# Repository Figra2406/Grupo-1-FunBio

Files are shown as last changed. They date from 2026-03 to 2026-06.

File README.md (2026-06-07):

# Grupo-1-FunBio
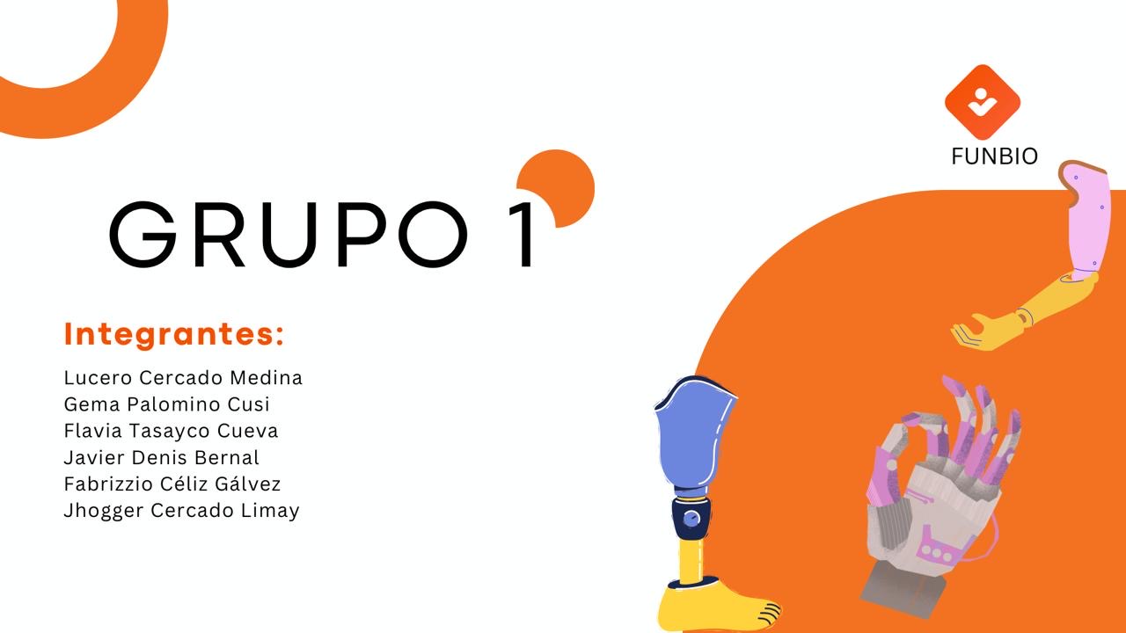
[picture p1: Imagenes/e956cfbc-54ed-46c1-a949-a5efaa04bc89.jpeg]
presentación

# Descripción de grupo
Grupo con el propósito de crear soluciones innovadoras en el area de ....., trabajando de forma colaborativa en el diseño y desarrollo del proyectos. 

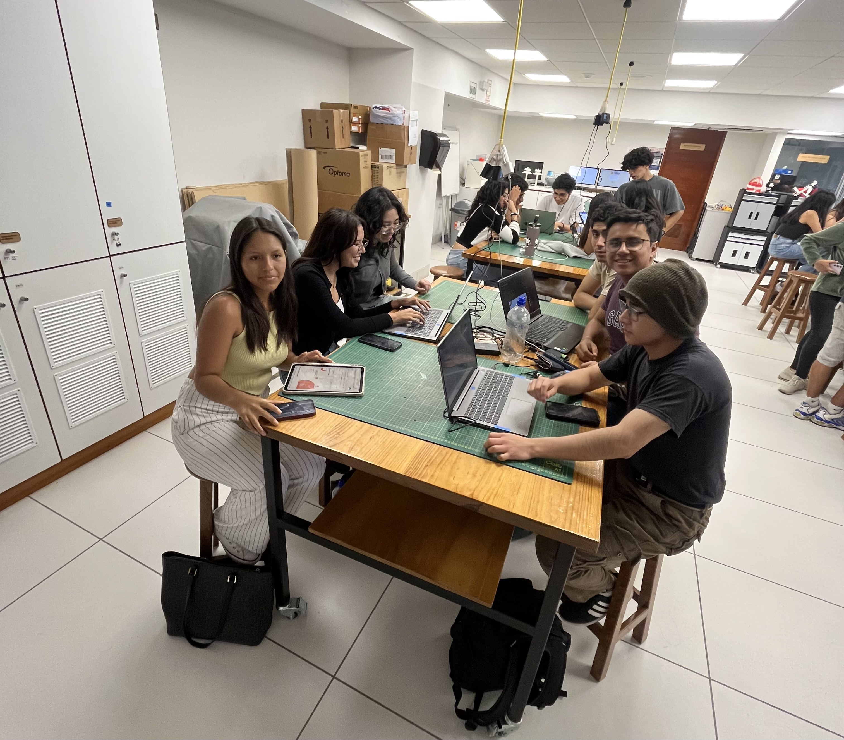
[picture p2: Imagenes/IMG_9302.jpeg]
Foto Grupal

Grupo enfocado en crear soluciones en el area de salud ante..., trabajando de forma colaborativa en el diseño y desarrollo del proyectos.
# Integrantes del Equipo y Roles
1. Lucero Cercado Medina
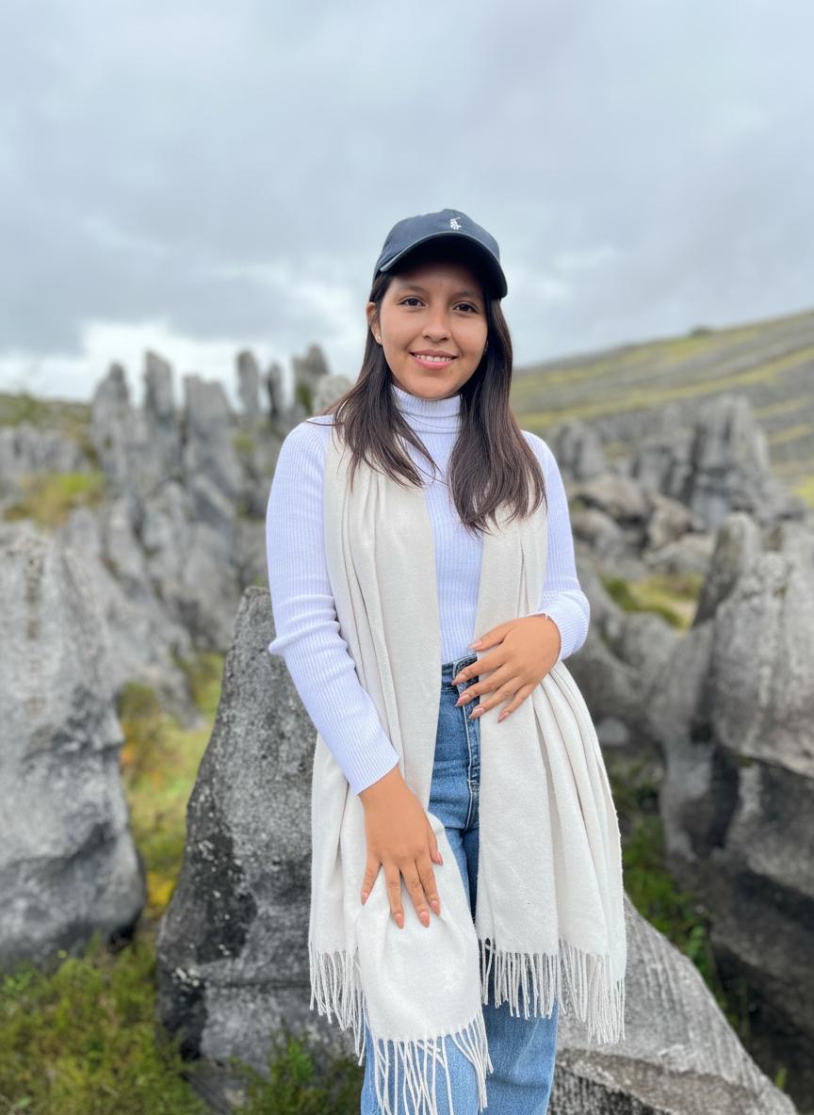
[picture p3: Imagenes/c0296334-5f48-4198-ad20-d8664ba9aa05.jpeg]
Lucero
   
   * **Edad:** 18 años
   * **Sobre mí:** Me interesa ingenieria de materiales y tejidos 
   * **Rol:** Impresión
   * **Responsabilidades:** Supervisar el proceso de impresión
3. Gema Palomino Cusi
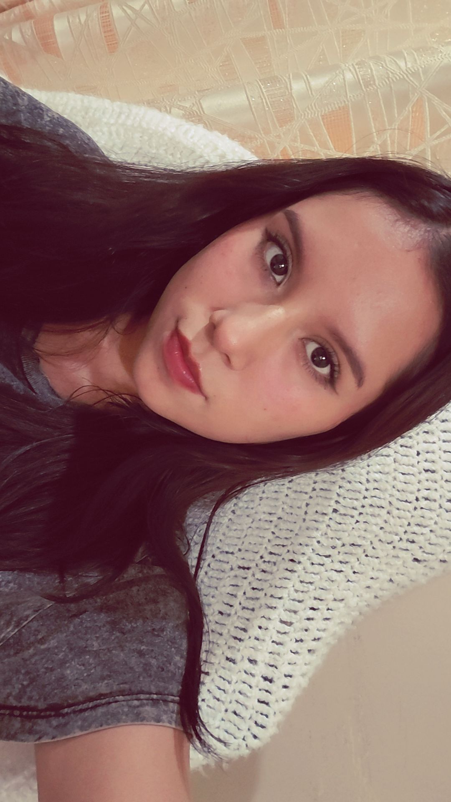
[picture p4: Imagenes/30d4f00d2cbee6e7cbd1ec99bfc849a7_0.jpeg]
Gema
   
   * **Edad:** 20 años
   * **Sobre mí:** Estudiante Biomédica PUCP-UPCH
   * **Rol:** Gestión 
   * **Responsabilidades:**
5. Flavia Tasayco Cueva
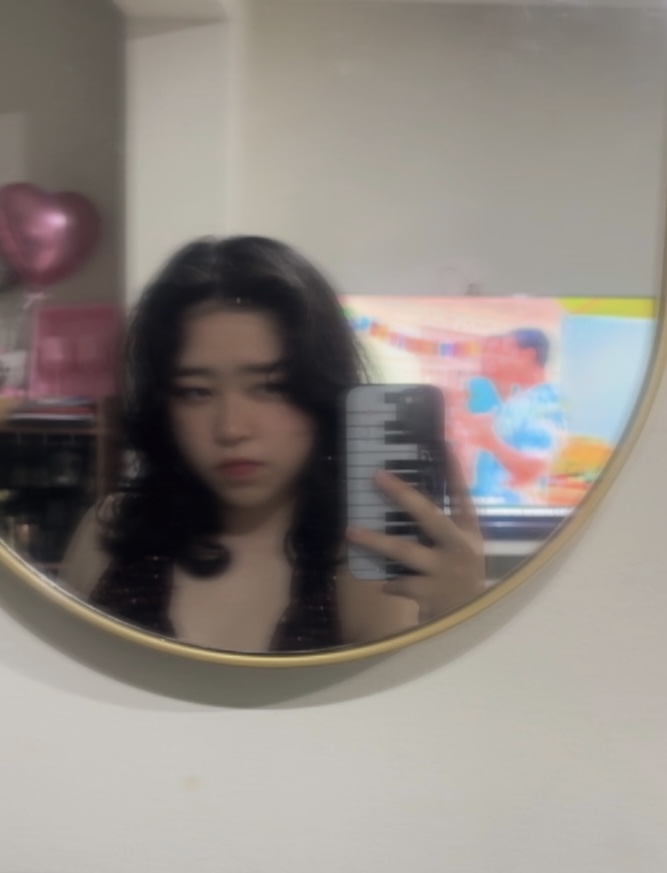
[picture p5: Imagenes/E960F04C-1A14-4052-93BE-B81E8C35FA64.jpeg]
Flavia
   
   * **Edad:** 19 años 
   * **Sobre mí:** Estudiante Biomédica PUCP-UPCH
   * **Rol:** Redacción
   * **Responsabilidades:**
7. Javier Bernal Garayar
   
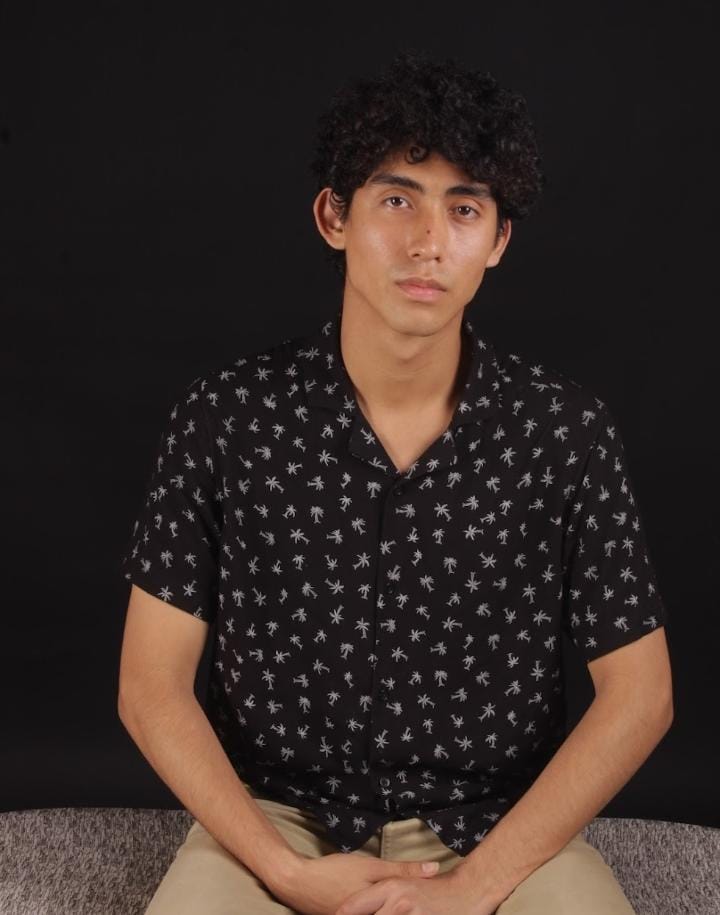
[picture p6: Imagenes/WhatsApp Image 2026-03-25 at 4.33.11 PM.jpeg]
Javier
   .
   * **Edad:** 24 años
   * **Sobre mí:**
   * **Rol:** Apoyo
   * **Responsabilidades:**
9. Fabrizzio Céliz Gálvez
    
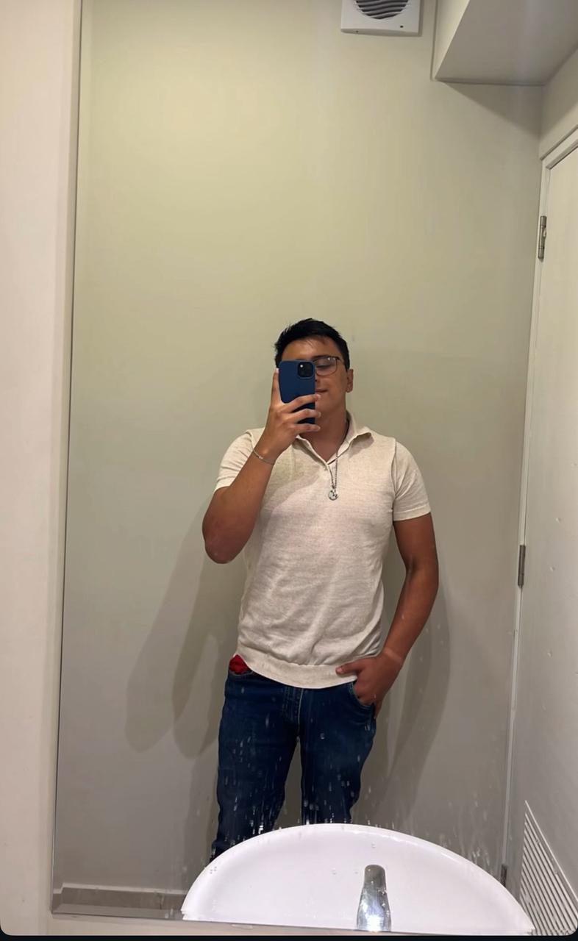
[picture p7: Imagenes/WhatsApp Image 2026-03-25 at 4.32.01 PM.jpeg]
Fabrizzio
   
   * **Edad:** 20 
   * **Sobre mí:** Estudiante de Ingenieria Biomedica PUCP-UPCH 
   * **Rol:** Diseñado y modelado 3D
   * **Responsabilidades:** 
11. Jhogger Cercado Limay

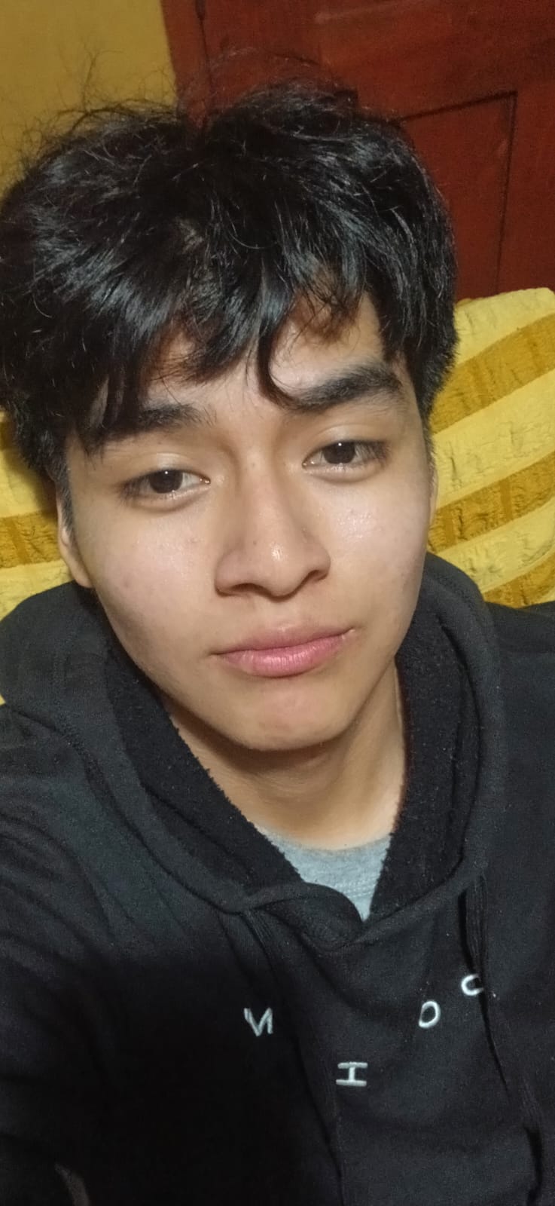
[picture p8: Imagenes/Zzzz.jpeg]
Jhogger
   .
   * **Edad:** 19 
   * **Sobre mí:**
   * **Rol:** 
   * **Responsabilidades:**

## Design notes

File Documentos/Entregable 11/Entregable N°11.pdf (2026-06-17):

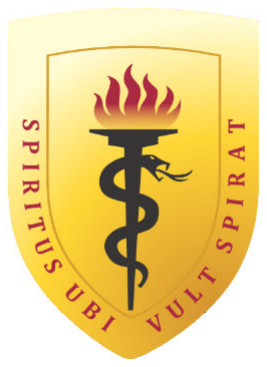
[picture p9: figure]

## FUNDAMENTOS DE BIODISEÑO

## Entrega N°11: Integración Hardware - Software - Manufactura Digital

## Grupo 1

## Integrantes: Fabrizzio Marcel Céliz Gálvez Jhogger Cercado Limay Ximena Gema Palomino Cusi Flavia Sharick Tasayco Cueva Javier Denis Bernal Garayar Lucero Rubi Cercado Medina

16/06/26

### 1. Verificación de diseño (Software):

Funcionalidad | Requerimiento | Resultado esperado | Resultado obtenido | ¿Cump le? | Observaciones
Inicio del sistema | El sistema debe iniciar el ciclo de alivio de presión de forma controlada. | Al encender el dispositivo, el programa debe iniciar sin activar accidentalmente bombas y servos. | En el código se inician los pines del ESP32 y se apagan bombas, válvulas/servos y buzzer antes de iniciar el ciclo. | Si | Se recomienda mantener esta condición inicial para evitar activaciones inesperadas al conectar la fuente
Activación del buzzer | El sistema debe indicar el inicio del periodo de alivio de presión. | El buzzer debe emitir una alerta antes de iniciar la terapia. | En el prototipo electrónico se evidencia que el buzzer se enciende por 2 segundos para advertir el inicio de la terapia. | Si | Esta función permite avisar al usuario o cuidador que el sistema comenzará a operar.
Activación de bombas de aire | El sistema debe inflar las bolsas de aire para redistribuir la presión. | Las bombas deben encenderse durante un tiempo programado para inflar los cojines. | En el prototipo electrónico se evidencia que las bombas de aire se encienden por 10 segundos para inflar los cojines. | Si | Se verificó el encendido de las bombas; falta medir presión o volumen de inflado para saber si es suficiente para uso real.
Control del tiempo de inflado | El sistema debe medir el tiempo de descarga mediante un cronómetro automático. | El software debe controlar automáticament e cuánto tiempo permanecen activas las bombas. | El código utiliza tiempos programados para inflado, mantenimiento, desinflado y espera. | Si | Se logró conseguir un rango de desinflado pero
Tiempo de terapia | El sistema debe mantener la redistribución de presión durante un periodo terapéutico. | Luego del inflado, las bolsas deben mantenerse infladas durante un tiempo determinado. | En el código realizado se utiliza un tiempo de 20 segundos para poder realizar pruebas pero se idea que se aumente a 3 minutos | Parcial mente | Falta evidenciar con una prueba completa que el sistema mantenga la presión durante el tiempo terapéutico planteado de aproximadamente 240 segundos.
Alerta sonora antes del descenso | El sistema debe emitir una alerta sonora al finalizar el tiempo programado de | El buzzer debe indicar que la terapia terminará y que el sistema retornará a su | En el prototipo electrónico se evidencia que el buzzer vuelve a activarse por 3 segundos antes del | Si | Esta función es necesaria porque anticipa el cambio de estado del sistema.

| alivio de presión. | estado inicial. | descenso del paciente.
Control del desinflado | El sistema debe permitir el retorno del usuario a la posición inicial después del periodo de descarga. | Los servos o válvulas deben liberar el aire de forma lenta y segura. | Los servos activan una pinza sobre uno de los tubos para liberar el aire de manera controlada. | Parcial mente | El mecanismo funciona de forma preliminar, pero falta medir el tiempo real de desinflado y comprobar si ambos cojines se desinflan de forma uniforme
Control bluetooth | El dispositivo debe permitir el accionamiento mediante control remoto o Bluetooth. | El usuario o cuidador debe poder iniciar el ciclo sin manipular directamente el circuito. | Se ha planteado el desarrollo de una aplicación para una interfaz bluetooth pero aún falta la implementación | No | El desarrollo de la aplicación se está realizando con diferentes pruebas pero por ahora su funcionalidad está enfocada principalmente en Android.
Detección de fallas del driver | El sistema debe operar de manera segura ante fallas eléctricas o de actuadores. | Si el DRV8833 detecta una falla, el sistema debe apagar bombas y activar un modo de emergencia. | En el código del se incluye una función de detección de falla mediante el pin NFAULT y un modo de emergencia que apaga bombas y abre válvulas. | Parcial mente | La función está programada en en el código pero aun faltan hacer pruebas de fallo y ajustar el prototipo para poder saber cómo actuará en estas situaciones desafortunadas.
Retorno al estado inicial | El sistema debe permitir que el usuario vuelva a la posición inicial luego del alivio de presión. | Al finalizar el ciclo, las bombas deben apagarse y el aire debe liberarse de manera controlada. | El prototipo apaga las bombas y activa los servos para liberar aire. | Parcial mente | Se verificó de forma preliminar, pero falta comprobar con carga o peso representativo si el retorno es seguro y estable.
Apagado del sistema | El cuidador o usuario debe poder apagar el sistema cuando sea necesario. | El sistema debe contar con una forma clara de apagado o interrupción. | En el diseño electrónico inicial se planea el uso de un switch de encendido pero aun no se han realizado pruebas finales. | Parcial mente | Se recomienda incluir un interruptor general accesible y una prueba de apagado seguro de energía.

### 2. Verificación de diseño (Hardware):

Requerimiento del diseño | Componen te evaluado | Pruebas realizadas | Resultados | ¿Cum ple? | Observaciones
El sistema debe controlar automáticament e el ciclo de alivio de presión | ESP32 | Verificar que el ESP32 pueda controlar buzzer, bombas y servos/válvulas | El ESP32 es usado como unidad de control y su funcionalidad es positiva. | Si | Se mantiene el ESP32 como controlador principal por su capacidad de control y posible conexión Bluetooth.
El sistema debe activar las bombas de aire | Bombas de aire | Verificar encendido de las bombas durante el tiempo programado | En el prototipado electrónico las bombas se activan por 10 segundos para inflar los cojines. | Si | Falta medir caudal, presión generada y tiempo necesario para inflado con carga real (aproximadamente es un tiempo menor)
El sistema debe controlar la etapa de potencia de las bombas | DRV8833 | Verificar que el driver permita el control de las bombas desde el microcontrolador. | El DRV8833 se usa como control principal de las bombas. | Si | Se debe cuidar que la corriente requerida por las bombas no supere la capacidad del driver.
El sistema debe redistribuir presión en la zona sacrocoxígea | Bolsas de aire | Verificar que las bolsas se inflen y se ubiquen a ambos lados de la región glútea. | Se usan dos bolsas de aire ubicadas en el asiento para redistribuir la presión. | Parcia lment e | Falta medir presión de contacto o realizar una prueba con carga para comprobar la redistribución real.
El sistema debe liberar el aire de forma controlada | Servomotor es | Verificar que el servo accione la pinza y permita el desinflado lento. | Se evidencia que los servos giran la pinza ubicada en el tubo de liberación de aire. | Parcia lment e | El mecanismo funciona, pero se debe mejorar la precisión mecánica y asegurar que el tubo no se dañe por presión repetida.
El diseño inicial consideraba válvulas solenoides | Válvulas solenoides | Verificar si se implementa la válvula en el prototipo final. | Previamente se pensó en el uso de una válvula solenoide, pero en el prototipo electrónico final se reemplaza funcionalmente por servos y pinza | No | Se considera un cambio de diseño. El uso de servos permitió una liberación mecánica del aire más accesible para el prototipo actual.
El sistema debe emitir señales auditivas | Buzzer | Verificar que el buzzer se active al inicio y antes del descenso. | El buzzer se activó por 2 segundos al inicio y por 3 | Si | Se recomienda mantenerlo como señal de seguridad para el cuidador y

| | | segundos antes de finalizar la terapia. | | usuario.
El sistema debe contar con alimentación eléctrica adecuada | Bateria | Verificar si la fuente o batería alimenta al ESP32, bombas y servos sin fallas. | Se plantea el uso de una batería recargable pero no se reporta una medición de autonomía ni caída de voltaje. | Parcia lment e | Falta medir autonomía, consumo total y estabilidad de voltaje.
El sistema debe proteger los componentes eléctricos | Fusible, Switch, Capacitores | Verificar la presencia de elementos básicos de protección y encendido. | Se considera bloque de alimentación, fusible, switch y capacitores. | Si | Falta comprobar la protección real ante sobrecorriente y mejorar el aislamiento de cables para un mejor uso.
El prototipo debe ser portátil y adaptable a una silla de ruedas | Carcasa | Verificar que la carcasa integre los componentes principales. | Se diseñó una carcasa rectangular con tapa desmontable, alojamientos para protoboard, batería, servos, bombas y regulador. | Parcia lment e | El diseño original planteado se mandó a imprimir pero aun falta las primeras pruebas de implementación de medidas.
Los componentes internos deben mantenerse fijos | Soportes internos | Verificar puntos de fijación para bombas, servos y protoboard. | El diseño de la carcasa incluye alojamientos y soportes atornillados para reducir desplazamiento s. | Parcia lment e | Falta prueba física de vibración o movimiento durante el funcionamiento.
El sistema debe permitir conexión de tubos hacia los cojines. | Mangueras | Verificar existencia de entradas/salidas para tubos. | La carcasa cuenta con dos orificios para los tubos que conectan cojines, bombas y servomotores. | Si | Se recomienda revisar que el radio de las mangueras no obstruya el flujo de aire.
El sistema debe mantener la estabilidad del usuario durante la elevación o redistribución | Bolsas de aire | Verificar que el usuario no se desplace durante el ciclo. | Aún no se evidencia una prueba con usuario real ni con peso equivalente. | No | Se deben realizar pruebas con pesos reales y finalmente con una persona con un peso considerable.

El sistema debe operar sin trasladar al usuario fuera de la silla | Implementa ción del prototipado | Verificar que el sistema pueda colocarse sobre el asiento de una silla convencional. | El concepto plantea un dispositivo portátil colocado sobre la silla de ruedas sin modificarla permanentemen te. | Parcia lment e | Faltan pruebas del prototipo instalado en una silla de ruedas real.
El sistema debe cumplir criterios básicos de seguridad | Integración completa | Verificar ausencia de movimientos bruscos, cables expuestos y calentamiento. | No se han realizado pruebas de temperatura, presión máxima, estabilidad corporal ni seguridad eléctrica completa. | Parcia lment e | Se recomienda realizar pruebas de calentamiento, estabilidad, deslizamiento, fugas de aire y funcionamiento prolongado.

### 3. Tabla de verificación del prototipo

FUNCIONALIDAD | CUMPLIMIENTO
SI | NO

El dispositivo infla las bolsas de aire mediante bombas de 6 V.

El dispositivo desinfla las bolsas de aire cuando se envía la orden correspondiente.

El ESP32 recibe comandos desde la aplicación móvil mediante Bluetooth.

La aplicación permite controlar manualmente el inflado y desinflado de las bolsas.

El sistema distribuye la presión alternadamente entre las zonas de apoyo.

El dispositivo funciona con batería recargable.

El sistema monitorea la presión interna de las bolsas mediante sensores.

El dispositivo evita sobrepresiones mediante límites programados.

La aplicación muestra el estado de funcionamiento del dispositivo.

El sistema almacena o transmite datos para su monitoreo.

4. Tabla de requerimientos iniciales, finales y resultados de test.
Requerimientos de diseños iniciales | Requerimientos de diseños finales | Expectativas del test
El sistema debe reducir la presión continua sobre la zona glútea del paciente. | Se implementaron dos bolsas de aire independientes controladas electrónicamente para redistribuir la presión. | Se verificó el llenado de presión entre ambas bolsas durante el funcionamiento.
El dispositivo debe ser portátil. | Se utilizó una batería recargable como fuente principal de alimentación. | Se espera que el sistema opere correctamente sin conexión directa a la red eléctrica.
Debe existir control inalámbrico del sistema. | Se implementó comunicación Bluetooth mediante ESP32 y una aplicación desarrollada en MIT App Inventor. | Se tiene la expectativa de que la conexión entre aplicación y dispositivo sea estable dentro del rango de operación.
El usuario debe poder inflar y desinflar las bolsas manualmente. | Se añadieron botones de control en la aplicación móvil. | Los comandos fueron creados y esperan ser ejecutados correctamente por las bombas neumáticas.
El dispositivo debe proteger al usuario frente a presiones excesivas. | Se programaron límites máximos de presión y rutinas de seguridad. | El sistema debería detener el inflado al alcanzar el valor establecido.
El equipo debe ser fácil de utilizar. | La interfaz móvil se diseñó con controles simples e indicadores de estado. | Los usuarios deberían operar el sistema sin capacitación extensa.
Debe permitir futuras ampliaciones del sistema. | El ESP32 proporciona suficientes entradas y salidas para incorporar nuevos sensores y funciones. | Se comprobó la posibilidad de integrar módulos adicionales.
El sistema debe ser de bajo costo. | Se emplearon componentes comerciales de fácil adquisición. | El costo estimado resultó inferior al de sistemas clínicos especializados.
Debe contribuir a la prevención de úlceras por presión. | El prototipo realiza cambios periódicos en la distribución de cargas mediante variaciones de presión. | Se espera una reducción de los puntos de presión estáticos durante las pruebas preliminares.

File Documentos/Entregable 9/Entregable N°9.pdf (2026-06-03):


## FUNDAMENTOS DE BIODISEÑO

## Entrega N°9: Modelado 3D y avance del prototipado electrónico.Plan de usabilidad basado en evidencias

## Grupo 1

## Integrantes: Fabrizzio Marcel Céliz Gálvez Jhogger Cercado Limay Ximena Gema Palomino Cusi Flavia Sharick Tasayco Cueva Javier Denis Bernal Garayar Lucero Rubi Cercado Medina

26/05/26

Hardware Electronico.
1)Diseño esquemático del circuito electrónico:

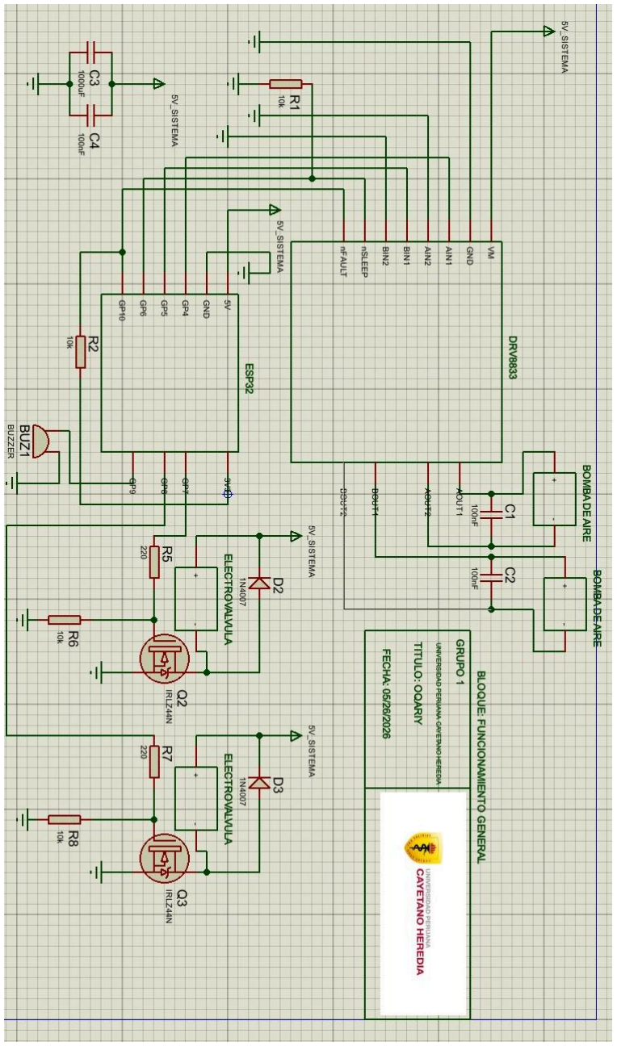
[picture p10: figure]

Software:
Script de programación:

const int PIN_BOMBA_IZQ = 4; const int PIN_BOMBA_DER = 5; const int PIN_NSLEEP = 6;

const int PIN_VALVULA_IZQ = 7; const int PIN_VALVULA_DER = 8;

const int PIN_BUZZER = 9;
const int PIN_NFAULT = 10;

const unsigned long TIEMPO_INFLADO = 8000; const unsigned long TIEMPO_MANTENER = 10000; const unsigned long TIEMPO_DESINFLADO = 5000; const unsigned long TIEMPO_ESPERA = 15000;

void setup() {
pinMode(PIN_BOMBA_IZQ, OUTPUT); pinMode(PIN_BOMBA_DER, OUTPUT); pinMode(PIN_NSLEEP, OUTPUT);

pinMode(PIN_VALVULA_IZQ, OUTPUT); pinMode(PIN_VALVULA_DER, OUTPUT);

pinMode(PIN_BUZZER, OUTPUT); pinMode(PIN_NFAULT, INPUT);

apagarBombas();
cerrarValvulas();
apagarBuzzer();

digitalWrite(PIN_NSLEEP, LOW);

delay(1000);
beep(200);
}

void loop() {
if (hayFallaDRV()) {
modoEmergencia();
return;
}

beep(100);
habilitarDRV();
cerrarValvulas();
encenderBombas();

unsigned long inicioInflado = millis();

while (millis() - inicioInflado < TIEMPO_INFLADO) { if (hayFallaDRV()) {
modoEmergencia();
return;

}
}

apagarBombas();

unsigned long inicioMantener = millis();

while (millis() - inicioMantener < TIEMPO_MANTENER) { if (hayFallaDRV()) {
modoEmergencia();
return;
}
}

abrirValvulas();
beep(300);

delay(TIEMPO_DESINFLADO);

cerrarValvulas();
deshabilitarDRV();

beep(150);
delay(150);
beep(150);

delay(TIEMPO_ESPERA);
}

void habilitarDRV() {
digitalWrite(PIN_NSLEEP, HIGH); }

void deshabilitarDRV() {
digitalWrite(PIN_NSLEEP, LOW);
}

void encenderBombas() {
digitalWrite(PIN_BOMBA_IZQ, HIGH); digitalWrite(PIN_BOMBA_DER, HIGH); }

void apagarBombas() {
digitalWrite(PIN_BOMBA_IZQ, LOW); digitalWrite(PIN_BOMBA_DER, LOW); }

void abrirValvulas() {
digitalWrite(PIN_VALVULA_IZQ, HIGH); digitalWrite(PIN_VALVULA_DER, HIGH); }

void cerrarValvulas() {
digitalWrite(PIN_VALVULA_IZQ, LOW); digitalWrite(PIN_VALVULA_DER, LOW); }

void encenderBuzzer() {

digitalWrite(PIN_BUZZER, HIGH); }

void apagarBuzzer() {
digitalWrite(PIN_BUZZER, LOW); }

void beep(unsigned long tiempo) { encenderBuzzer();
delay(tiempo);
apagarBuzzer();
}

bool hayFallaDRV() {
return digitalRead(PIN_NFAULT) == LOW; }

void modoEmergencia() {
apagarBombas();
deshabilitarDRV();
abrirValvulas();

for (int i = 0; i < 5; i++) { beep(300);
delay(200);
}

delay(5000);
cerrarValvulas();
}

Plan de Usabilidad Basado en Evidencias

### 1. Contexto de uso

El dispositivo está dirigido a pacientes con lesión medular cervical que presentan movilidad reducida y dificultades para realizar cambios posturales de manera independiente. Se desarrolló considerando el caso de un paciente masculino de 28 años con lesión medular cervical C4 incompleta, quien permanece largos periodos sentado en una silla de ruedas y presenta un alto riesgo de desarrollar úlceras por presión debido a la presión continua ejercida sobre la región glútea [1–3].

El sistema está diseñado para utilizarse tanto en el hogar como en hospitales y centros de rehabilitación, donde los pacientes permanecen largos periodos en posición sedente durante actividades diarias, sesiones terapéuticas y procesos de rehabilitación física. Su función principal es redistribuir la presión acumulada mediante una elevación parcial de la pelvis, reduciendo la carga sobre las tuberosidades isquiáticas y favoreciendo la circulación sanguínea en los tejidos sometidos a presión prolongada [1,2].

La propuesta incorpora una estructura elevadora integrada a la silla de ruedas, bandas neumáticas para estabilización de miembros inferiores y un sistema electrónico automatizado compuesto por un ESP32, una mini bomba de aire, una válvula solenoide, un driver DRV8833 y un buzzer. Considerando las recomendaciones clínicas para la prevención de úlceras por presión en usuarios de silla de ruedas con lesión medular, se propone que el dispositivo realice una descarga de presión automática cada 20 minutos, manteniendo la elevación durante 90 segundos. Esta frecuencia se encuentra dentro del rango recomendado por las guías clínicas, las cuales sugieren realizar alivios de presión cada 15 a 30 minutos para favorecer la recuperación del flujo sanguíneo y disminuir el riesgo de lesión tisular [1–3].

Evidencia utilizada

Estado del arte

- La patente Wheelchair Structure for Preventing Pressure Ulcers propone cambios posturales periódicos para disminuir la presión prolongada sobre la región glútea [6].
- La silla de ruedas Quickie IRIS utiliza tecnología tilt-in-space para redistribuir presión y reducir el riesgo de úlceras por presión [7].

Modelado 3D y diseño electrónico

- El modelado 3D permitió verificar la integración del soporte elevador, la bolsa de aire y los sistemas de estabilización dentro de la silla de ruedas.
- El esquema electrónico incorpora un ESP32, mini bomba de aire, válvula solenoide, driver DRV8833, buzzer y batería recargable para automatizar el funcionamiento del sistema.

El temporizador programado en el ESP32 permite ejecutar automáticamente la frecuencia de descarga establecida.

### 2. Perfil del usuario

El usuario principal es un paciente con lesión medular cervical C4 incompleta que presenta movilidad severamente reducida, dependencia parcial para realizar cambios posturales y permanencia prolongada en silla de ruedas. Conserva movimientos cervicales funcionales, capacidades cognitivas preservadas y comprensión adecuada de instrucciones [3].

Desde el punto de vista emocional y social, el paciente busca recuperar independencia funcional y reincorporarse progresivamente a sus actividades académicas y sociales. Sin embargo, debido a sus limitaciones motoras, depende del apoyo de un cuidador para diversas actividades de la vida diaria.

Estas características influyen directamente en el diseño del prototipo, ya que se prioriza la automatización del sistema, la facilidad de uso y la incorporación de mecanismos de estabilización que permitan realizar cambios posturales seguros sin requerir esfuerzo físico significativo por parte del usuario [4,5].

Evidencia utilizada

- Los pacientes con lesión medular cervical presentan limitaciones para realizar alivios de presión de manera independiente [3].

- El diseño centrado en el usuario recomienda adaptar las características del producto a las necesidades físicas y funcionales del usuario final [4,5].
3. Análisis de tareas
N° | Tarea | Responsable | Criticidad
1 | Verificar estado de carga de la batería | Cuidador | Baja
2 | Colocar correctamente al usuario en la silla | Cuidador | Alta
3 | Ajustar correas de seguridad | Cuidador | Alta
4 | Colocar bolsas de aire | Cuidador | Alta
5 | Encender el sistema | Cuidador/Usuari o | Media
6 | Activar el ciclo de descarga de presión | Sistema | Alta
7 | Inflar bolsas de aire | Sistema | Alta
8 | Elevar parcialmente | Sistema | Crítica
9 | Mantener estabilidad corporal | Sistema | Crítica
10 | Ejecutar tiempo de descarga programado | Sistema | Media
11 | Retornar a la posición | Sistema | Crítica
12 | Apagar el sistema | Cuidador/Usuari o | Baja

Las tareas críticas corresponden a la elevación del usuario, la estabilización corporal y el retorno seguro a la posición inicial, ya que están directamente relacionadas con la seguridad del usuario y la efectividad de la redistribución de presión [1,2,6].

4. Criterios de éxito
Eficacia | Eficiencia | Satisfacción | Seguridad
Lograr que el sistema complete el ciclo automatizado de alivio de presión | Lograr que todo el proceso automático de elevación y el periodo de alivio se ejecute dentro del rango ideal de 1 a 2 minutos | Lograr que el paciente califique el dispositivo (mayor a 80 puntos en la encuesta SUS), | Garantizar que ocurran cero deslizamientos o movimientos bruscos del paciente y tener 0 lesiones

Bibliografía

[1] Sonenblum SE, Vonk TE, Janssen TWJ, Sprigle SH. Effects of wheelchair cushions and pressure relief maneuvers on ischial interface pressure and blood flow in people with spinal cord injury. Arch Phys Med Rehabil. 2014;95(7):1350-1357.
[2] Smit CAJ, Zwinkels M, van Dijk T, et al. Gluteal blood flow and oxygenation during electrical stimulation-induced muscle activation versus pressure relief movements in wheelchair users with spinal cord injury. Spinal Cord. 2013;51(9):694-699.
[3] Consortium for Spinal Cord Medicine. Pressure ulcer prevention and treatment following spinal cord injury: a clinical practice guideline for health-care professionals. Washington (DC): Paralyzed Veterans of America; 2021.
[4] International Organization for Standardization. ISO 9241-210:2019. Ergonomics of human-system interaction—Human-centred design for interactive systems. Geneva: ISO; 2019.
[5] International Organization for Standardization. ISO 62366-1:2015. Medical devices—Application of usability engineering to medical devices. Geneva: ISO; 2015.
[6] Yang HP, Chen KY, Liu YE, Wu YH, Yeh SC. Wheelchair structure for preventing pressure ulcers. US Patent Application Publication No. US20240016680A1. 2024.
[7] Sunrise Medical. Quickie IRIS Tilt-in-Space Wheelchair. Fresno (CA): Sunrise Medical.

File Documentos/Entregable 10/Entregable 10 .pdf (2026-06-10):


## FUNDAMENTOS DE BIODISEÑO

## Entrega N°10: AVANCE DE FABRICACION DIGITAL 1. PROTOTIPADO

ELECTRÓNICO.

## Grupo 1

## Integrantes: Fabrizzio Marcel Céliz Gálvez Jhogger Ubaldo Cercado Limay Ximena Gema Palomino Cusi Flavia Sharick Tasayco Cueva Javier Denis Bernal Garayar Lucero Rubi Cercado Medina

09/06/26

### 1. Prototipado electrónico:

Se adjunta el link del github donde se encuentra el video del funcionamiento del prototipado. El funcionamiento para este ejemplo es el siguiente:
- Primero un buzzer se enciende por 2 segundos para advertir sobre el inicio de la terapia
- Luego las bombas de aire se encienden por 10 segundos para inflar los cojines y elevar al paciente
- Posteriormente al apagado de las bombas se vuelve a encender el mismo buzzer por 3 segundos para indicar que se va a dar por finalizada la terapia y se va a descender al paciente
- Finalmente los servos se activan girando una pinza que se hizo a uno de los tubos de liberación de aire, el servo gira varias veces para poder realizar la liberación de aire de manera lenta y segura.
Link de evidencia audiovisual: https://github.com/Figra2406/Grupo-1-FunBio/blob/main/Documentos/Entregable%2010/Prot otipado%20Electronico%20Grupo%201.mp4 (https://github.com/Figra2406/Grupo-1-FunBio/blob/main/Documentos/Entregable%2010/Prototipado%20Electronico%20Grupo%201.mp4)

### 2. Avance de Fabricación digital:

Descripción del modelado 3D y animación del prototipo

En el enlace adjunto se presenta el modelado 3D de la carcasa del prototipo desarrollado en Fusion, junto con una animación que muestra el despiece y la distribución de sus componentes principales. La estructura consiste en una caja rectangular con tapa desmontable, la cual se fija mediante cuatro tornillos ubicados en las esquinas para garantizar la protección y portabilidad del sistema.

El diseño incluye alojamientos específicos para el protoboard, la batería recargable, dos servomotores, dos bombas de aire y el regulador de voltaje, considerando los puntos de fijación necesarios para asegurar cada componente. Asimismo, se incorporaron soportes atornillados para las bombas de aire, con el fin de evitar desplazamientos durante el transporte o funcionamiento del dispositivo.

La carcasa también cuenta con dos orificios de entrada para los tubos que conectarán los cojines con las bombas y servomotores, así como perforaciones destinadas a facilitar la salida del sonido del buzzer instalado en el protoboard. La animación permite visualizar el ensamblaje de la caja, la ubicación de cada elemento y la integración de todos los componentes dentro del sistema.

La evidencia audiovisual se encuentra subida en el github en el apartado …/Documentos/Entregable10, con el nombre “Video despiece Grupo 1”.

### 3. Plan de usabilidad:

Contexto de uso

El dispositivo está dirigido a pacientes con lesión medular cervical que presentan movilidad reducida y dificultades para realizar cambios posturales de manera independiente. Su diseño se desarrolló considerando el caso de un paciente masculino de 28 años con lesión medular cervical C4 incompleta, quien permanece largos periodos sentado en una silla de ruedas y presenta un alto riesgo de desarrollar úlceras por presión debido a la presión continua sobre la región glútea y el coxis, consecuencia de la imposibilidad de realizar alivios de presión sin asistencia [1–3].

El sistema ha sido concebido como un dispositivo portátil que se coloca sobre el asiento de una silla de ruedas convencional, permitiendo su uso sin realizar modificaciones permanentes a la estructura de la silla. Está diseñado para emplearse en el hogar, hospitales y centros de rehabilitación, donde los pacientes permanecen en posición sedente durante actividades cotidianas, sesiones terapéuticas o periodos prolongados.

El dispositivo incorpora dos bolsas de aire ubicadas en el asiento, a ambos lados de la región glútea. Durante su funcionamiento, estas bolsas se inflan de manera controlada para redistribuir la presión hacia las zonas laterales de apoyo y disminuir la carga ejercida sobre la región del coxis, favoreciendo su descarga de presión. Posteriormente, las bolsas se desinflan de forma automática para que el usuario recupere su posición inicial. Este cambio periódico en la distribución de las cargas contribuye a mantener la perfusión tisular y a disminuir el riesgo de desarrollar úlceras por presión en pacientes que permanecen largos periodos sentados [1–3].

El funcionamiento del sistema es gestionado por un controlador ESP32, el cual coordina el accionamiento de dos bombas de aire para el inflado de las bolsas de aire y de dos servomotores que liberan la presión en un tubo de escape de aire el cual permite controlar su desinflado. El usuario o cuidador puede iniciar el ciclo mediante una interfaz inalámbrica basada en Bluetooth, mientras que el sistema ejecuta automáticamente la secuencia de inflado, mantiene la redistribución de presión durante aproximadamente 90 segundos y posteriormente desinfla las bolsas para retornar al estado inicial. Se propone que este ciclo se repita cada 50 minutos, intervalo que se encuentra dentro de las recomendaciones internacionales para la prevención de úlceras por presión en personas con lesión medular, las cuales indican realizar alivios de presión cada 35 a 60 minutos para preservar la irrigación sanguínea de los tejidos y prevenir lesiones por presión [1–3].

Evidencia utilizada

Modelado 3D y diseño electrónico

- El modelado 3D permitió verificar la integración de los componentes electrónicos, el soporte elevador y la bolsa de aire.
- El esquema electrónico incorpora un ESP32, mini bomba de aire, servomotores, driver DRV8833, buzzer y batería recargable para automatizar el funcionamiento del sistema.

El temporizador programado en el ESP32 permite ejecutar automáticamente la frecuencia de descarga establecida.

Perfil del usuario

El usuario presenta una movilidad severamente reducida que limita su capacidad para realizar cambios posturales de forma independiente, por lo que permanece sentado durante largos periodos y requiere apoyo parcial de un cuidador para prevenir complicaciones asociadas a la inmovilidad. Sin embargo, conserva movimientos cervicales funcionales, capacidades cognitivas preservadas y una adecuada comprensión de instrucciones, lo que le permite interactuar con una interfaz de control sencilla y comprender el funcionamiento del dispositivo [3].

Desde el punto de vista emocional y social, busca recuperar la mayor independencia funcional posible y reincorporarse progresivamente a sus actividades académicas y sociales. Debido a sus limitaciones motoras, la dependencia del cuidador para realizar cambios posturales representa una barrera para su autonomía y calidad de vida [4,5].

Estas características orientan el diseño del prototipo hacia un sistema portátil, intuitivo y de fácil utilización, que automatiza el proceso de redistribución de presión mediante el inflado y desinflado controlado de bolsas de aire integradas en el asiento. Asimismo, incorpora mecanismos de estabilización que permiten realizar el alivio de presión de forma segura, minimizando el esfuerzo físico requerido por el usuario y reduciendo la carga del cuidador durante su utilización [4,5].

Como usuario secundario se considera al cuidador, quien se encarga de colocar el dispositivo, supervisar su funcionamiento e iniciar o detener el ciclo cuando sea necesario. Por ello, el sistema también está diseñado para ser fácil de instalar, seguro e intuitivo, favoreciendo su uso tanto en el hogar como en entornos hospitalarios y de rehabilitación.

Evidencia utilizada

- Los pacientes con lesión medular cervical presentan limitaciones para realizar alivios de presión de manera independiente [3].
- El diseño centrado en el usuario recomienda adaptar las características del producto a las necesidades físicas y funcionales del usuario final [4,5].

Análisis de tareas

N° | Tarea | Responsable | Criticidad
1 | Verificar estado de carga de la batería | Cuidador | Baja
2 | Colocar correctamente al usuario en la silla | Cuidador | Alta
3 | Ajustar correas de seguridad | Cuidador | Alta
4 | Colocar bolsas de aire | Cuidador | Alta
5 | Encender el sistema | Cuidador/Usuario | Media
6 | Activar el ciclo de descarga de presión | Sistema | Alta
7 | Inflar bolsas de aire | Sistema | Alta

8 | Elevar parcialmente | Sistema | Crítica
9 | Mantener estabilidad corporal | Sistema | Crítica
10 | Ejecutar tiempo de descarga programado | Sistema | Media
11 | Retornar a la posición | Sistema | Crítica
12 | Apagar el sistema | Cuidador/Usuario | Baja

Las tareas críticas corresponden a la elevación del usuario, la estabilización corporal y el retorno seguro a la posición inicial, ya que están directamente relacionadas con la seguridad del usuario y la efectividad de la redistribución de presión [1,2].

Criterios de éxito

Eficacia | Eficiencia | Satisfacción | Seguridad
Lograr que el sistema complete el ciclo automatizado de alivio de presión | Lograr que todo el proceso automático de elevación y el periodo de alivio se ejecute dentro del rango ideal de 1 a 2 minutos | Lograr que el paciente califique el dispositivo (mayor a 80 puntos en la encuesta SUS), | Garantizar que ocurran cero deslizamientos o movimientos bruscos del paciente y tener 0 lesiones

Bibliografía

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

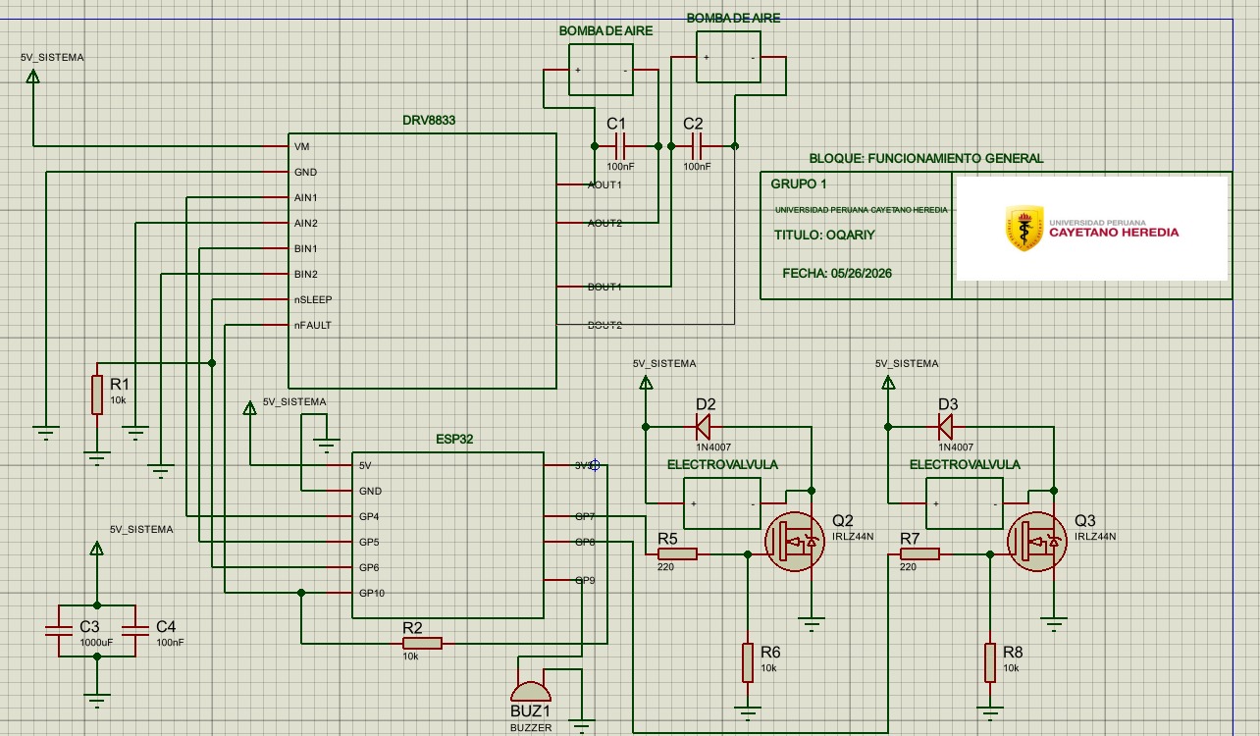
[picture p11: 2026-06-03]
Documentos/Entregable 9/Esquema Electronico.jpeg

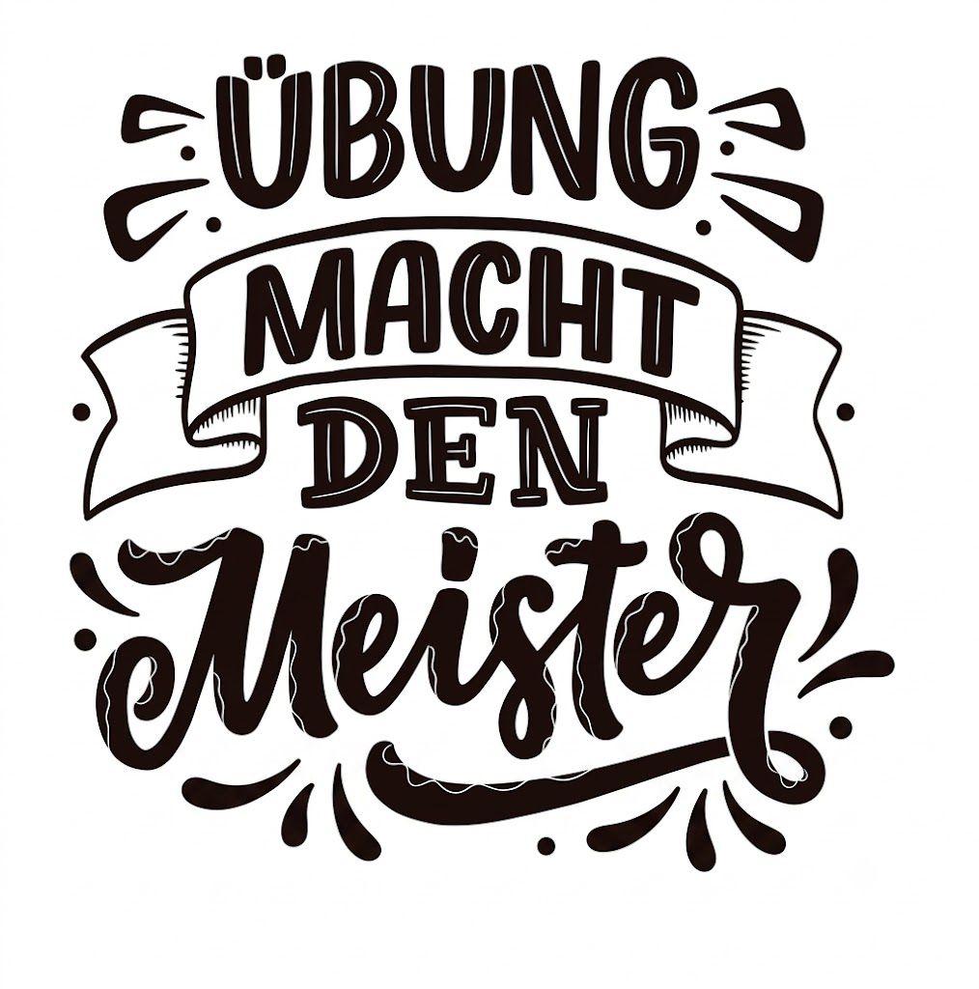
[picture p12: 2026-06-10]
Taller 10/Imagen_actividad2.jpg

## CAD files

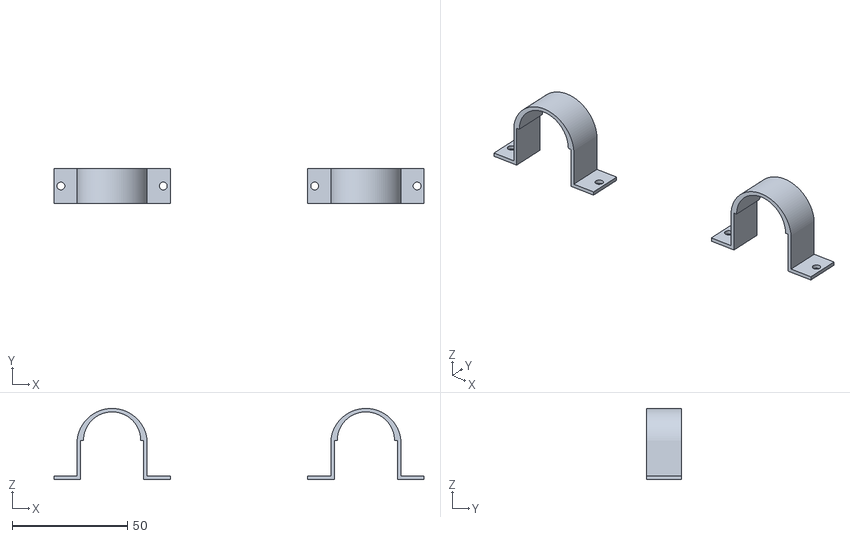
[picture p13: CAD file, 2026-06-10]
Documentos/Entregable 10/SEGURO.stl
160.4 x 15.0 x 30.8

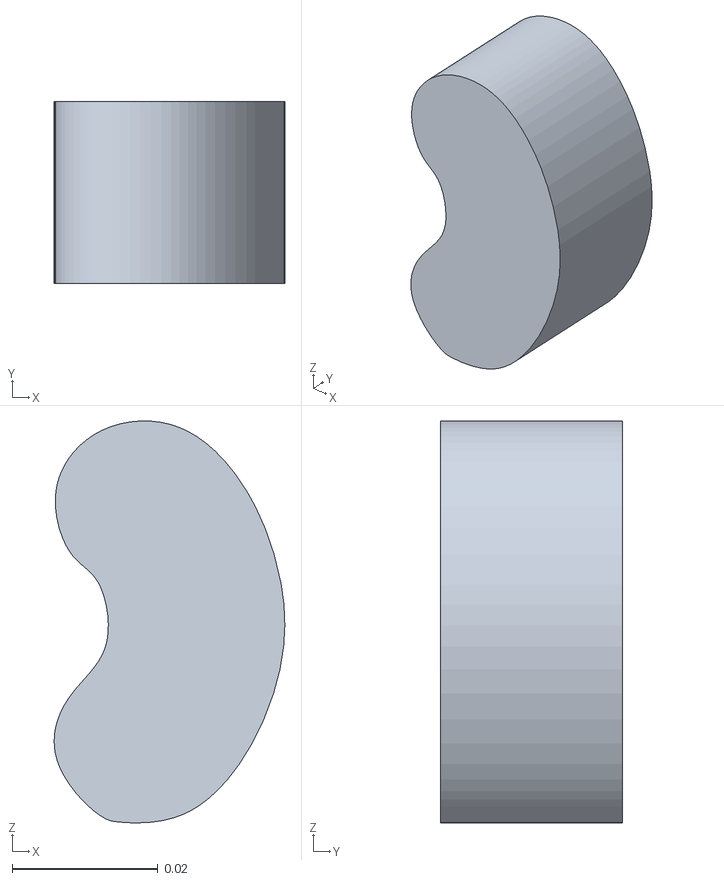
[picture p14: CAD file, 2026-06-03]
Documentos/Entregable 9/Soporte de elevación.stl
0.0317 x 0.025 x 0.0552

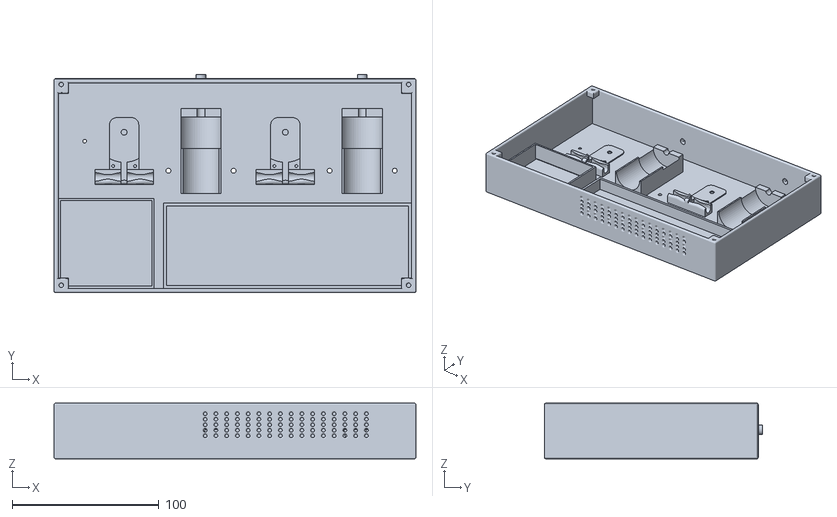
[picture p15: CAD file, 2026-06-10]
Documentos/Entregable 10/Carcasa.stl
247.0 x 149.0 x 38.0

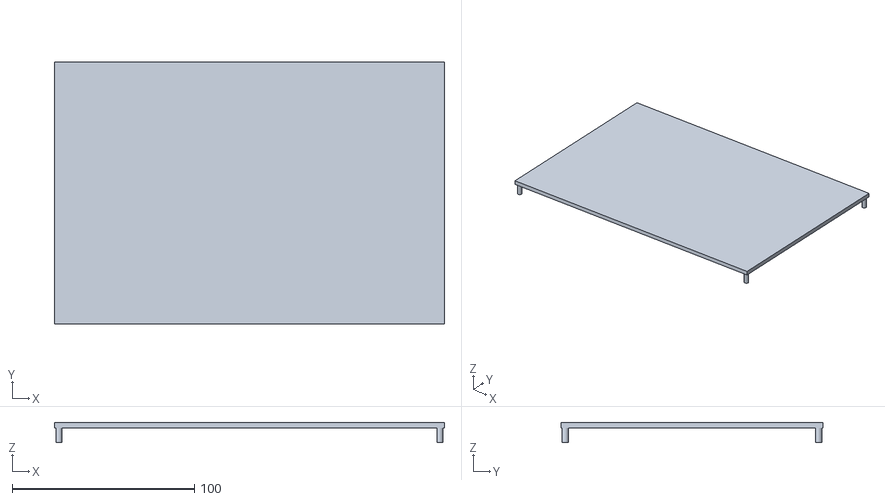
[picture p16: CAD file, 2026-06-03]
Documentos/Entregable 9/Tapa.stl
214.0 x 144.0 x 11.0

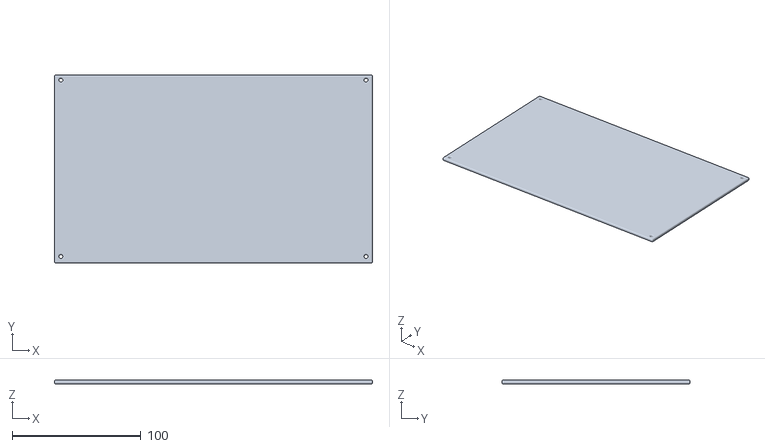
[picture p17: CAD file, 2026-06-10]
Documentos/Entregable 10/TAPA.stl
247.0 x 146.0 x 3.00

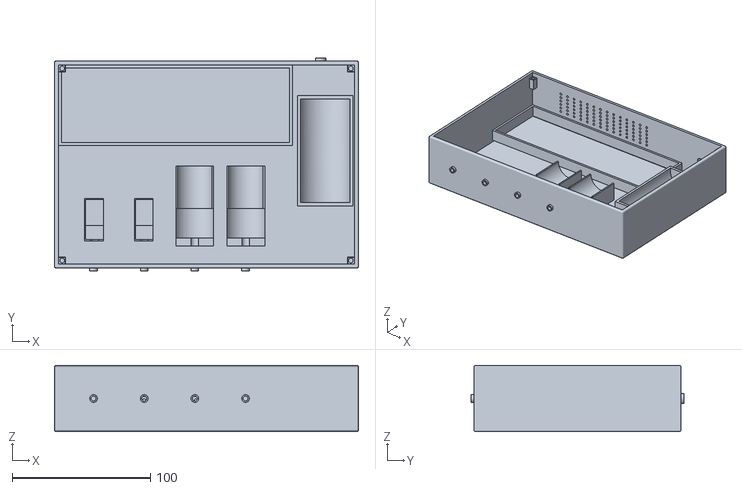
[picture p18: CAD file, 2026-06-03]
Documentos/Entregable 9/Caja.stl
220.0 x 154.0 x 48.0

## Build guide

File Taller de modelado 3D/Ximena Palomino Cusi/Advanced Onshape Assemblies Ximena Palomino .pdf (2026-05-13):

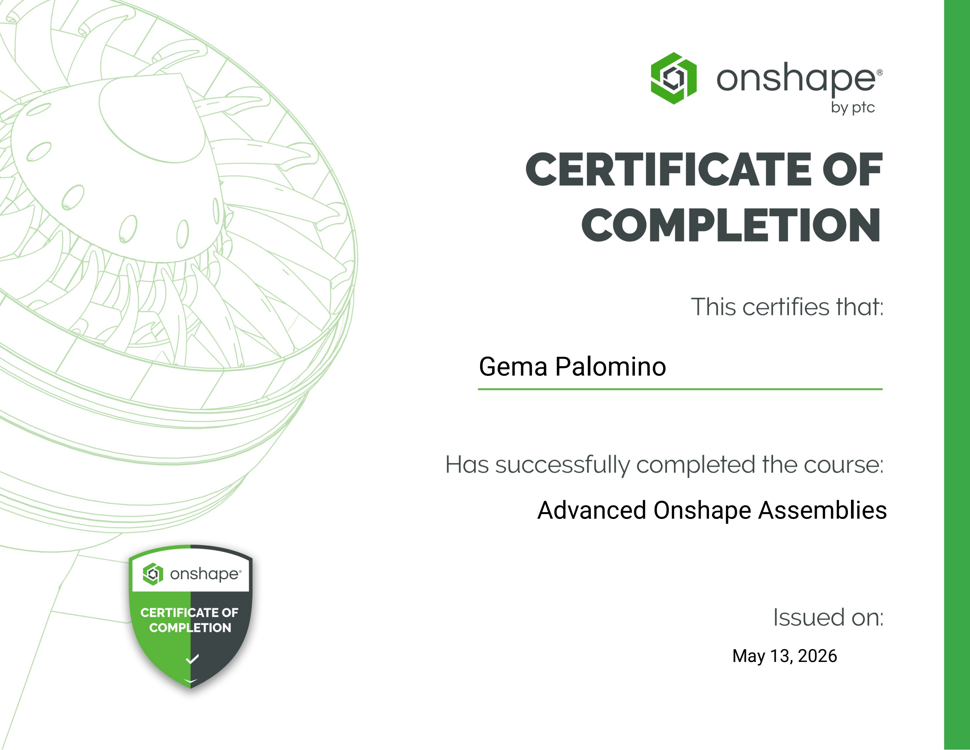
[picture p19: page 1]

Gema Palomino

Advanced Onshape Assemblies

May 13, 2026

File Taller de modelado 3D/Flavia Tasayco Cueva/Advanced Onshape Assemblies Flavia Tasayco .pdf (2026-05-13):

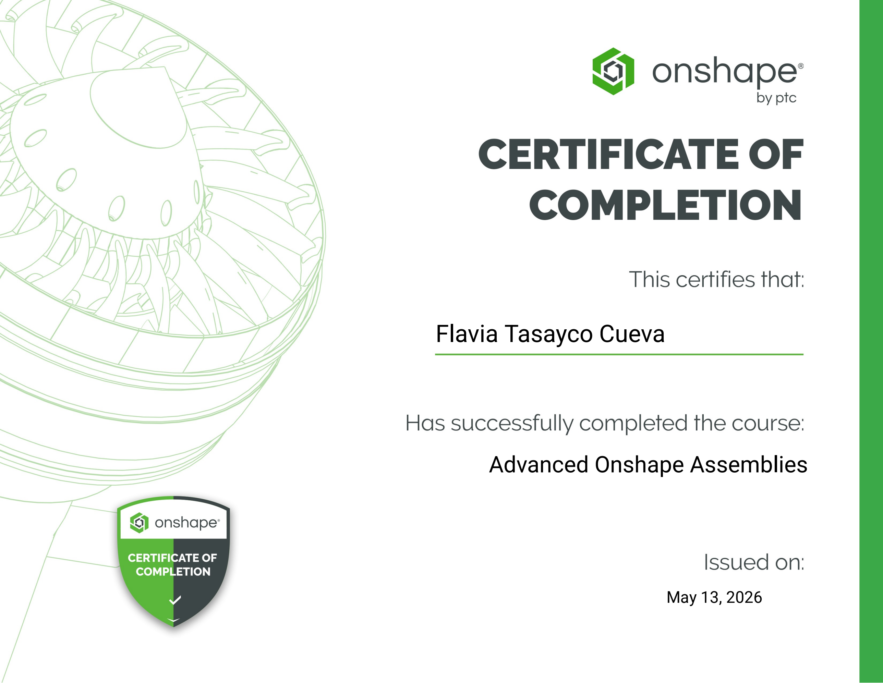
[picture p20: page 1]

Flavia Tasayco Cueva

Advanced Onshape Assemblies

May 13, 2026

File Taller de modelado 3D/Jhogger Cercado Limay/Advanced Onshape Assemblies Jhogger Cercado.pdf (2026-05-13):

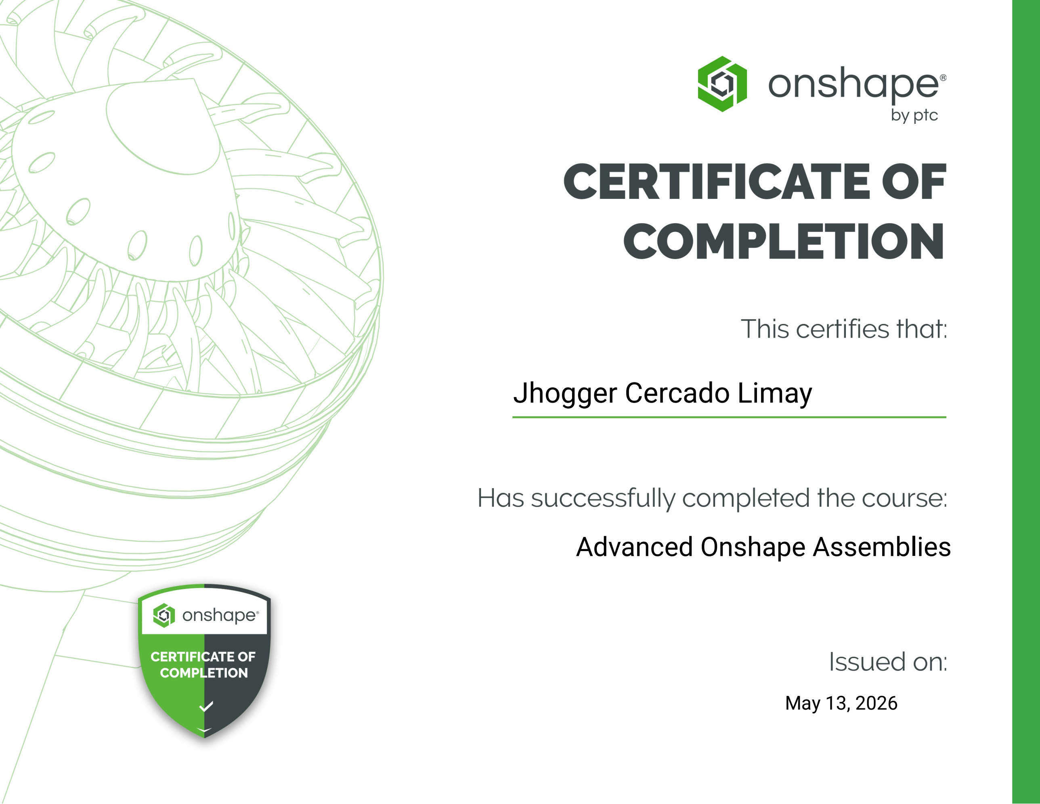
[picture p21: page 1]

Jhogger Cercado Limay

Advanced Onshape Assemblies

May 13, 2026

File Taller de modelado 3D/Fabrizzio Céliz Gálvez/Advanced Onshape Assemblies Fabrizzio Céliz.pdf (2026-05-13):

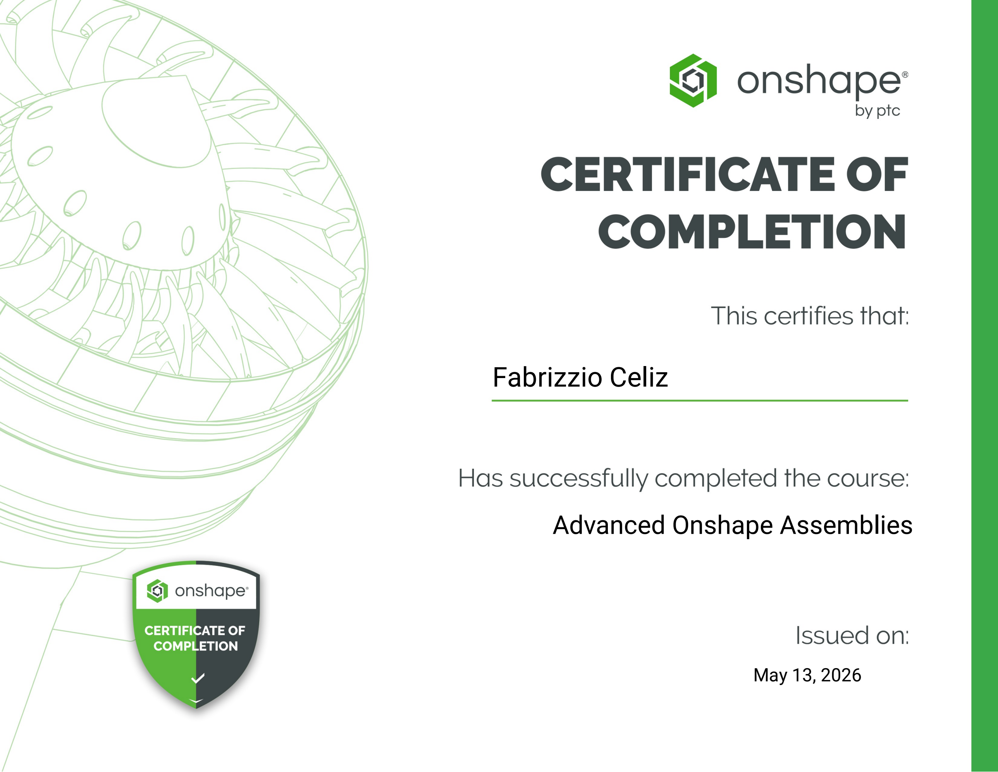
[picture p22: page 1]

Fabrizzio Celiz

Advanced Onshape Assemblies

May 13, 2026

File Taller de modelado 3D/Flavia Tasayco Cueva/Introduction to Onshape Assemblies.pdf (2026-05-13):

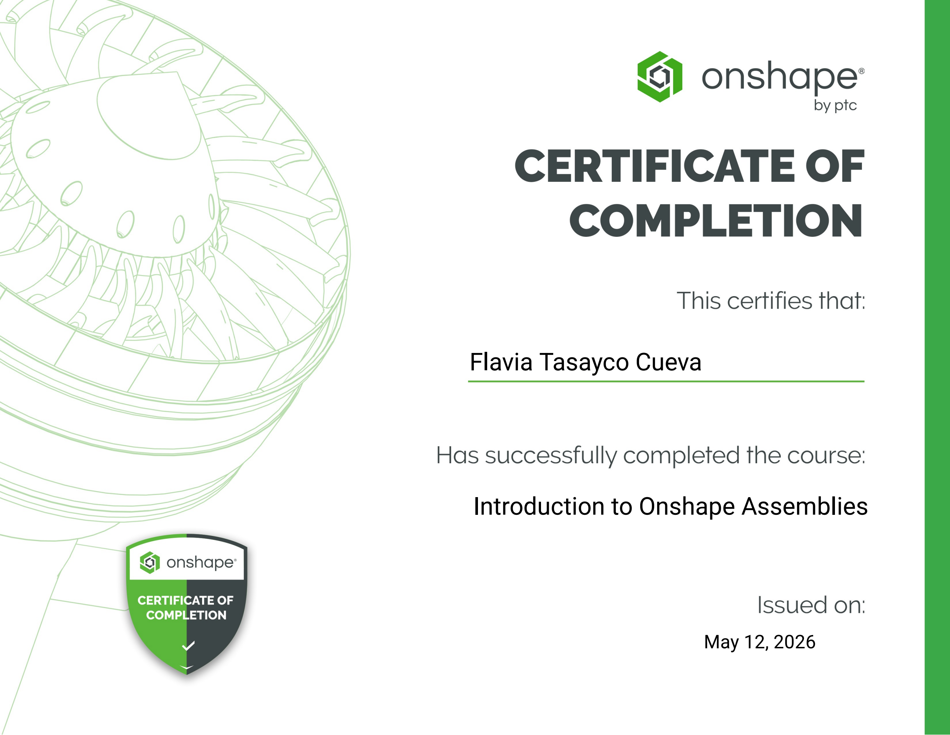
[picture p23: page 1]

Flavia Tasayco Cueva

May 12, 2026

Introduction to Onshape Assemblies

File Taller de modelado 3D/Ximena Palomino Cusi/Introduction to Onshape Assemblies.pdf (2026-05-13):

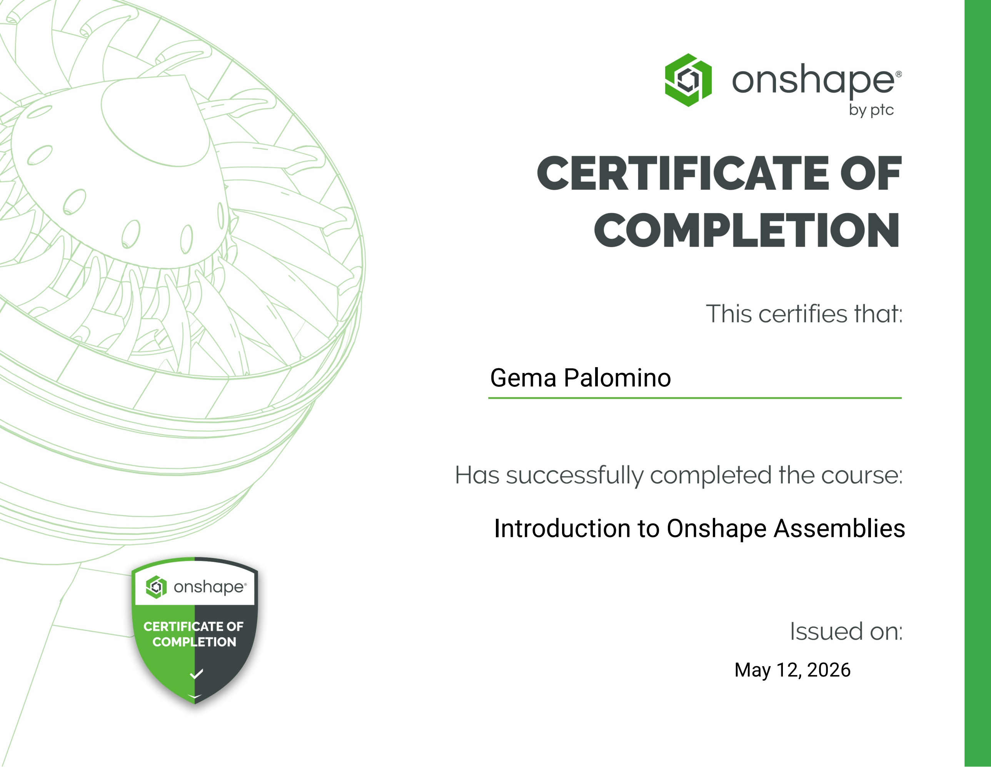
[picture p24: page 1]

Gema Palomino

May 12, 2026

Introduction to Onshape Assemblies

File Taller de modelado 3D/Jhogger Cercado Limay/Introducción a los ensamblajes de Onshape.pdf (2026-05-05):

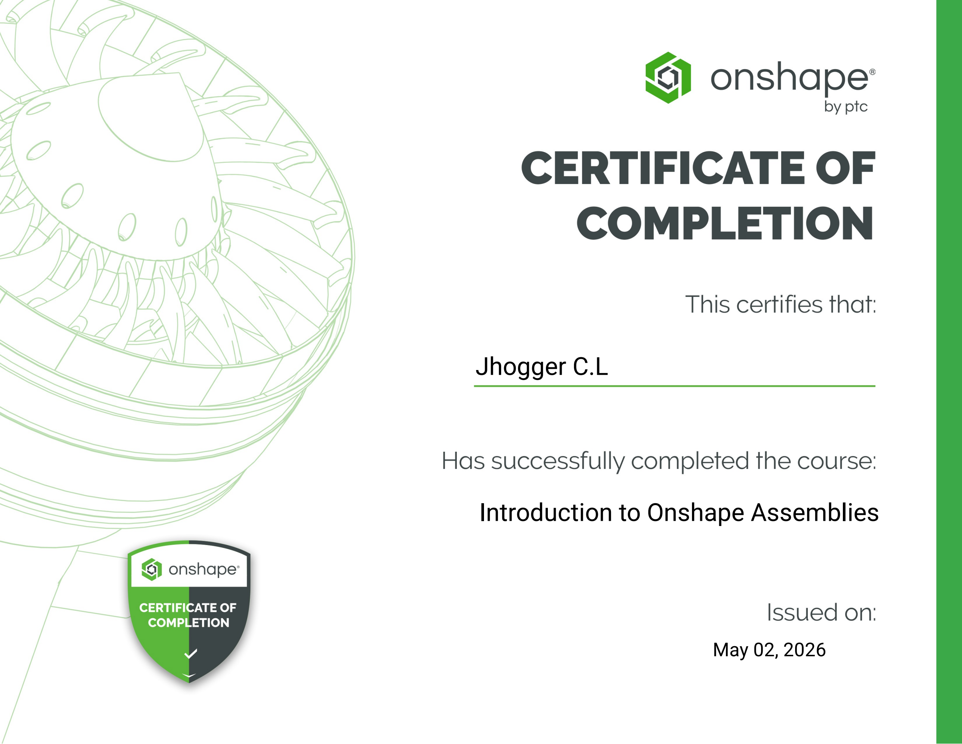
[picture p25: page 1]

Jhogger C.L

May 02, 2026

Introduction to Onshape Assemblies

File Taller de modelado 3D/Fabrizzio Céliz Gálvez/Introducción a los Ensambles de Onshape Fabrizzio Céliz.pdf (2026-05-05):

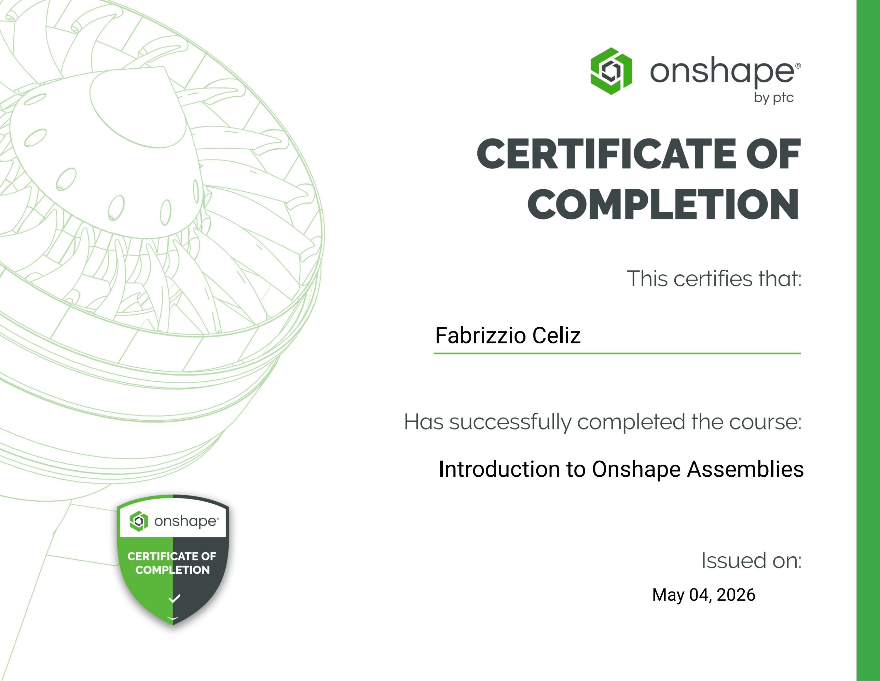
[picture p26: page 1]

Fabrizzio Celiz

May 04, 2026

Introduction to Onshape Assemblies

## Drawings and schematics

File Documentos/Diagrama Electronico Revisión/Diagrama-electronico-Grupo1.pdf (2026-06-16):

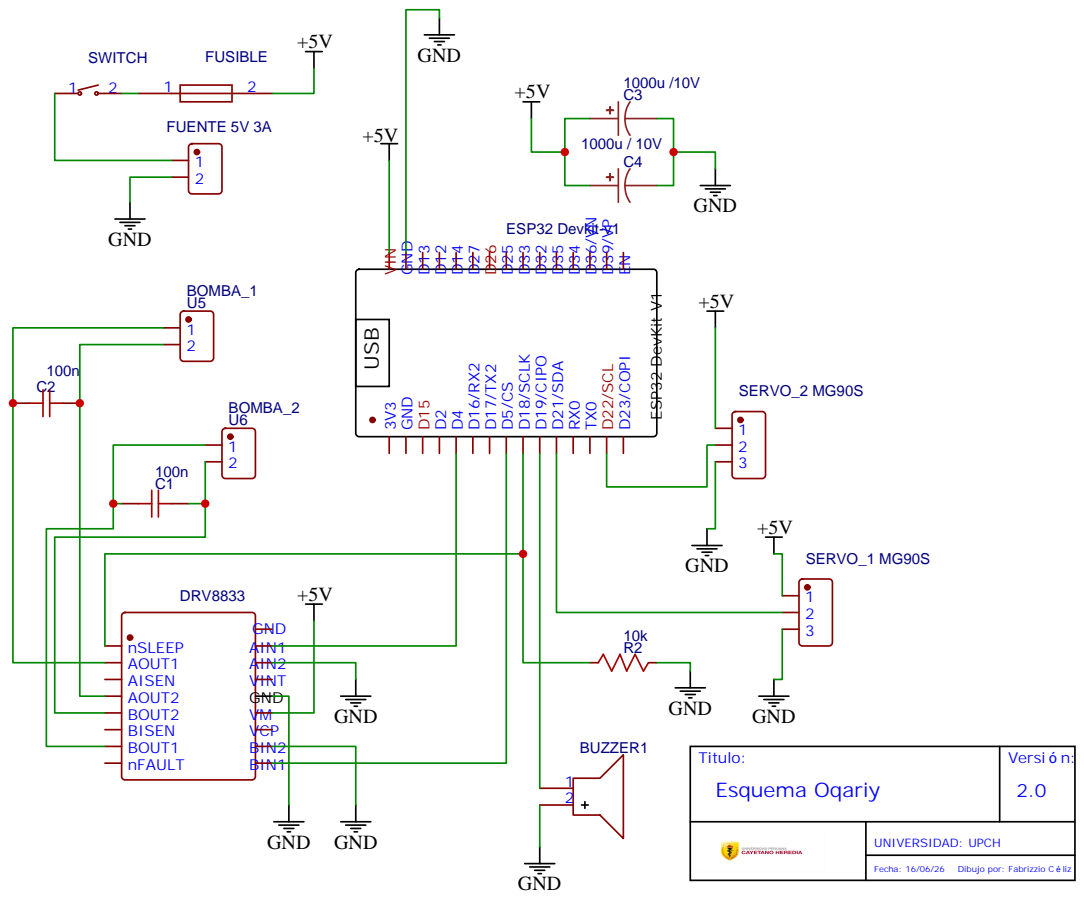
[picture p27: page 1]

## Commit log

2026-03-30 Se añadio ficha de datos del caso.
2026-04-07 Se añadio un avance para el entregable 2 sobre la tecnologia
2026-04-09 Se añadio las preguntas para la doctora
2026-04-14 Se añadio avance para el entregable 3
2026-04-21 Se ordenaron algunos documentos y se añadio avance de entregable 4
2026-04-21 Se cambio el avance 4
2026-05-05 Carpeta de Certificados
2026-05-13 Taller de modelado
2026-06-03 Entregable 9
    [Entregable 9 .stl]
2026-06-03 Esquemas Entregable 9
    [Entregable 9 pt2.stl]
2026-06-03 Se elimino archivos del entregable 9
    [Entregable 9 .stl, Entregable 9 pt2.stl]
2026-06-03 Se añadio el entregable 9
    [Caja.stl, Soporte de elevación.stl, Tapa.stl]
